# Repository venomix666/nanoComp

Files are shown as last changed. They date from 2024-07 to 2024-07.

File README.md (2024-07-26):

Simple carrier board for the Tang Nano 20K, intended for computer applications.   

The following features interfaces are available:
* USB-C power input with diode protection to avoid back-powering when Tang Nano 20K USB cable is connected
* On/Off switch
* Power LED
* Two USB type A ports.
* UART header for FTDI TTL-232R-3V3 cable
* GPIO header
* Power header with 5V and 3V3 available

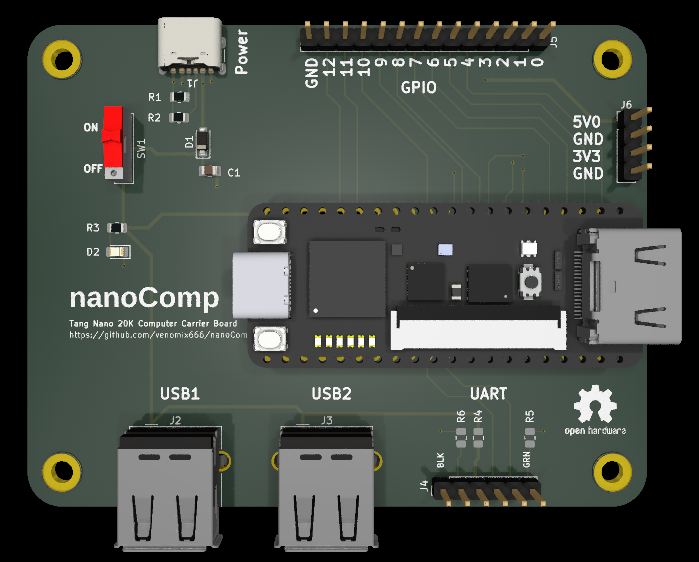
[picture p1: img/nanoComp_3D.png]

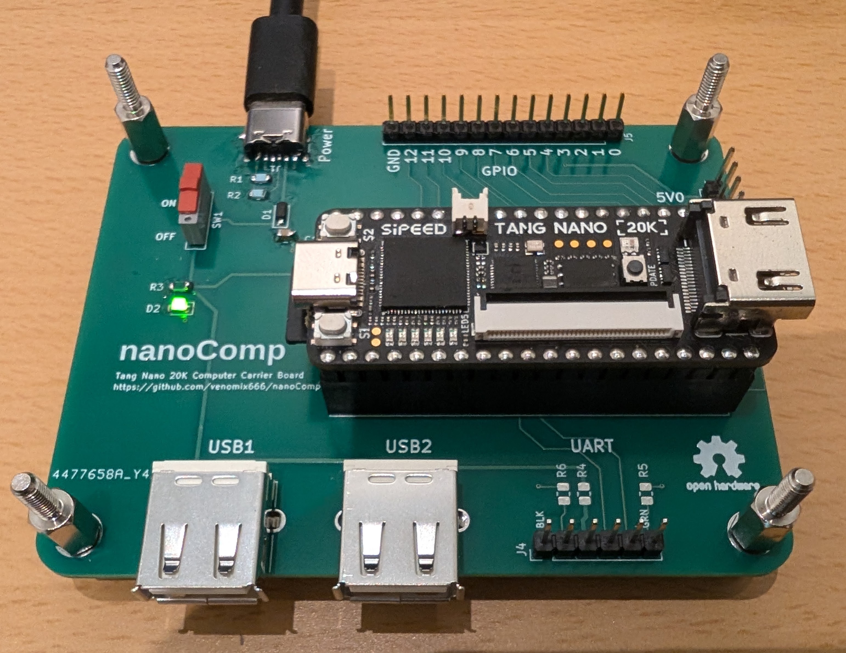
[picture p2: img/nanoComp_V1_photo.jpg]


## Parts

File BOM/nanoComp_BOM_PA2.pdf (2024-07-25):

nanoComp_BOM_PA2

Page 1

nanoComp BOM PA2

# | Reference | Qty | Value | Manufacturer | Manufacturer P/N | Supplier | Supplier P/N

1 | C1 | 1 1uF | | Generic | | Mouser | 603-CC805KKX7R7BB105
2 | D1 | 1 1N5819HW-7-F | | Diodes Inc | 1N5819HW-7-F | Mouser | 621-1N5819HW-F
3 D2 | | 1 LED | | Bivar | SM0805UGC | Mouser | 749-SM0805UGC
4 | J1 | 1 USB_C_Receptacle_PowerOnly_6P | | GCT | USB4125-GF-A | Mouser | 640-USB4125-GF-A
5 | J2,J3 | 2 USB_A | | Molex | 67643-3910 | Mouser | 538-67643-3910
6 J4 | | 1 Conn_01x06_Pin | | Generic | | Mouser | 855-M20-9990646
7 | J5 | 1 Conn_01x14 | | Generic | | Mouser | 538-22-28-4146
8 J6 | | 1 Conn_01x04 | | Generic | | Mouser | 538-22-28-4042
9 R1,R2 | | 2 5k1 | | Generic | | Mouser | 594-MCU08050C5101FP5
10 | R3 | 1 1k | | Generic | | Mouser | 71-TNPW08051K00FEEA
11 | R7,R8,R9,R10 | 4 15k | | Generic | | Mouser | 603-RT0805FRE0715KL
12 | SW1 | 1 SW_Wuerth_450301014042 | | Wurth | 450301014042 | Mouser | 710-450301014042
13 | U1 | 1 N/A | | Sipeed | Tang Nano 20k

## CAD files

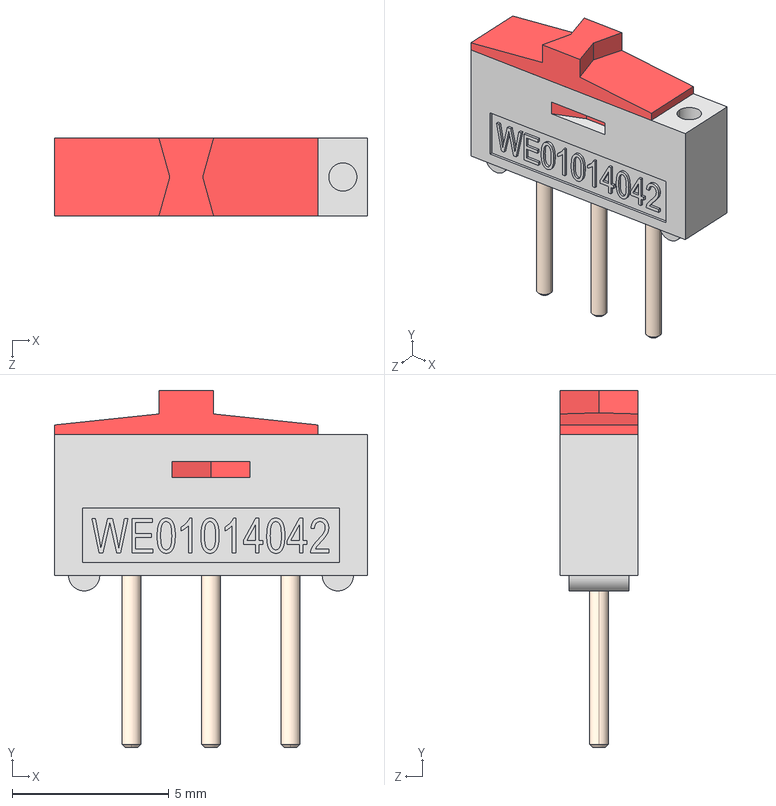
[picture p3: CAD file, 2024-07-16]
3D_models/450301014042.stp
10.0 x 11.4 x 2.50 mm

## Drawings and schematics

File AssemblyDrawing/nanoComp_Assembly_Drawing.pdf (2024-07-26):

1 | 2 | 3 | 4 | 5 | 6

A

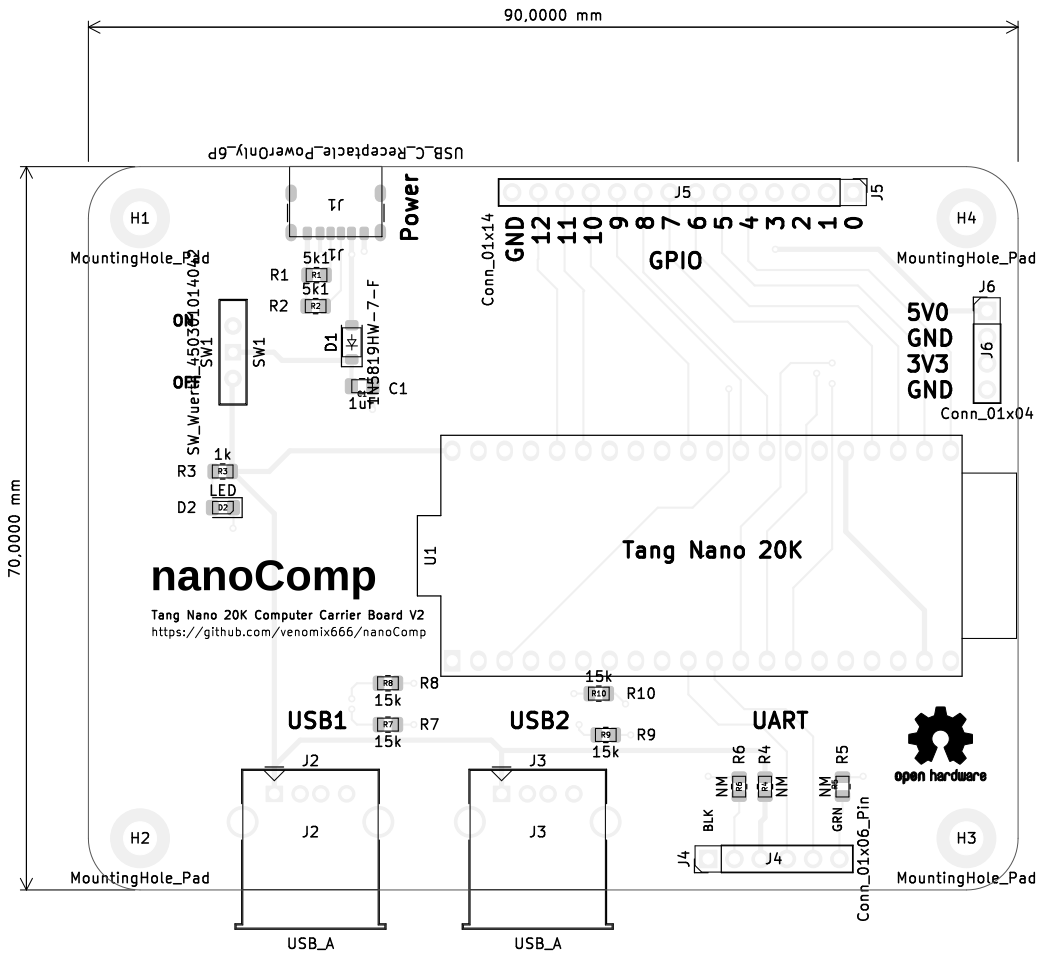
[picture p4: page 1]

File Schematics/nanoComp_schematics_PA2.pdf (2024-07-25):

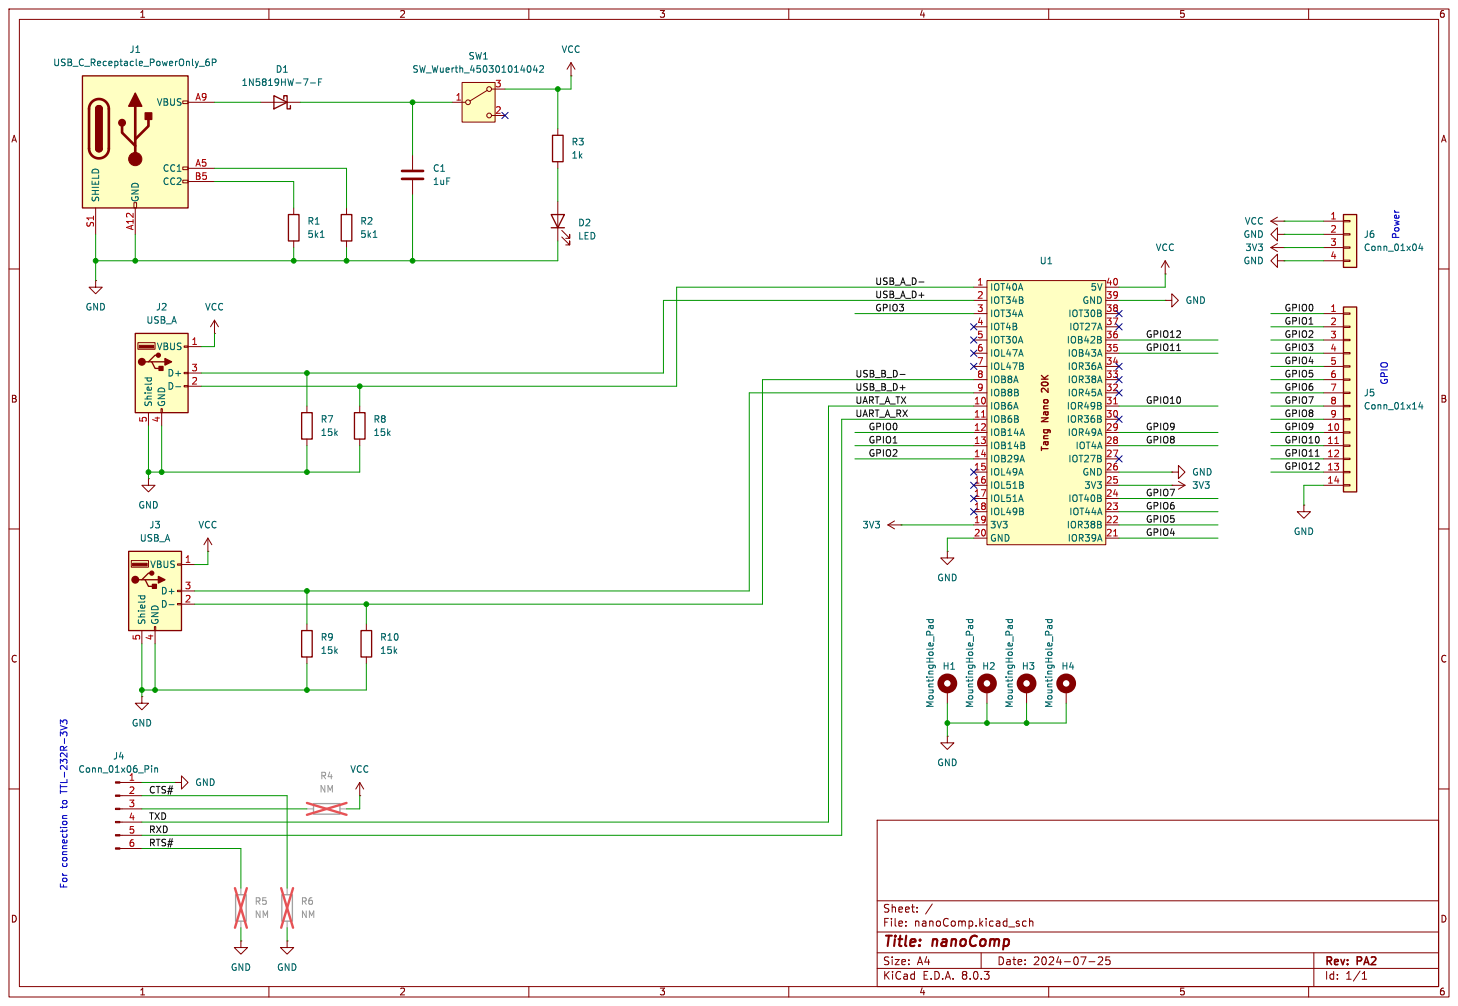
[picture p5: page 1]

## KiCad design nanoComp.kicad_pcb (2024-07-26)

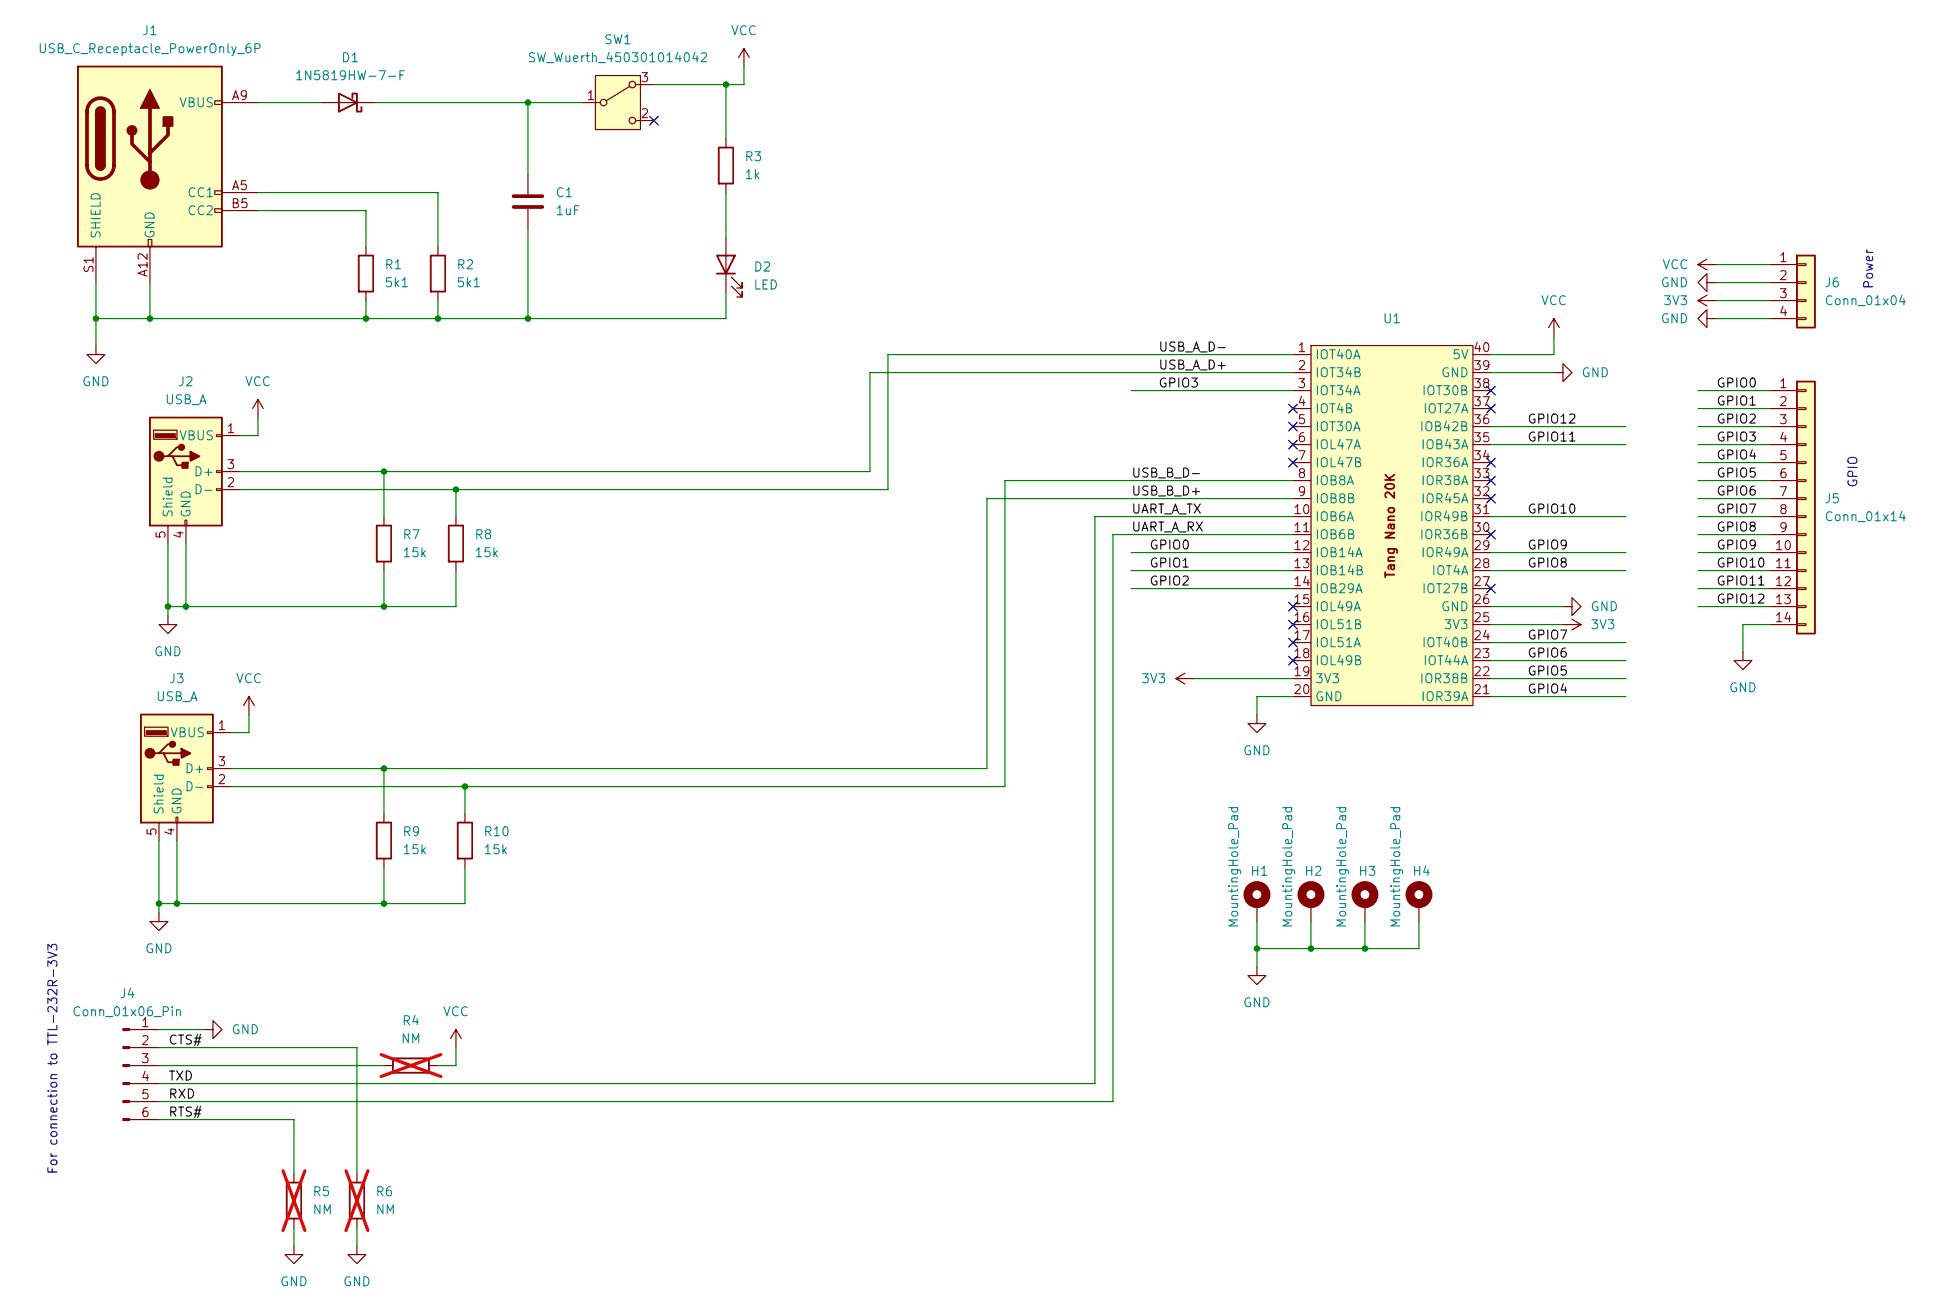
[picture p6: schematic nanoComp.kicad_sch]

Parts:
C1: 1uF; C_0805_2012Metric_Pad1.18x1.45mm_HandSolder
D1: 1N5819HW-7-F; D_SOD-123; Manufacturer P/N 1N5819HW-7-F
D2: LED; LED_0805_2012Metric_Pad1.15x1.40mm_HandSolder; Manufacturer P/N SM0805UGC
H1, H2, H3, H4: MountingHole_Pad; MountingHole_3.2mm_M3_ISO7380_Pad
J1: USB_C_Receptacle_PowerOnly_6P; USB_C_Receptacle_GCT_USB4125-xx-x-0190_6P_TopMnt_Horizontal; Manufacturer P/N USB4125-GF-A
J2, J3: USB_A; USB_A_Molex_67643_Horizontal; Manufacturer P/N 67643-3910
J4: Conn_01x06_Pin; PinHeader_1x06_P2.54mm_Vertical
J5: Conn_01x14; PinHeader_1x14_P2.54mm_Vertical
J6: Conn_01x04; PinHeader_1x04_P2.54mm_Vertical
R1, R2: 5k1; R_0805_2012Metric
R3: 1k; R_0805_2012Metric
R4, R5, R6: NM; R_0805_2012Metric; not fitted
R7, R8, R9, R10: 15k; R_0805_2012Metric
SW1: SW_Wuerth_450301014042; SW_Slide-03_Wuerth-WS-SLTV_10x2.5x6.4_P2.54mm; Manufacturer P/N 450301014042
U1: tangnano20k

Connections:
3V3: J6.3, U1.19 (3V3), U1.25 (3V3)
/CTS#: J4.2, R6.2
/GPIO0: J5.1, U1.12 (IOB14A)
/GPIO1: J5.2, U1.13 (IOB14B)
/GPIO2: J5.3, U1.14 (IOB29A)
/GPIO3: J5.4, U1.3 (IOT34A)
/GPIO4: J5.5, U1.21 (IOR39A)
/GPIO5: J5.6, U1.22 (IOR38B)
/GPIO6: J5.7, U1.23 (IOT44A)
/GPIO7: J5.8, U1.24 (IOT40B)
/GPIO8: J5.9, U1.28 (IOT4A)
/GPIO9: J5.10, U1.29 (IOR49A)
/GPIO10: J5.11, U1.31 (IOR49B)
/GPIO11: J5.12, U1.35 (IOB43A)
/GPIO12: J5.13, U1.36 (IOB42B)
/RTS#: J4.6, R5.2
/RXD: J4.5, U1.11 (IOB6B)
/TXD: J4.4, U1.10 (IOB6A)
/USB_A_D+: J2.3 (D+), R7.1, U1.2 (IOT34B)
/USB_A_D-: J2.2 (D-), R8.1, U1.1 (IOT40A)
/USB_B_D+: J3.3 (D+), R9.1, U1.9 (IOB8B)
/USB_B_D-: J3.2 (D-), R10.1, U1.8 (IOB8A)
GND: C1.2, D2.1 (K), H1.1, H2.1, H3.1, H4.1, J1.A12 (GND), J1.B12 (GND), J1.S1 (SHIELD), J2.4 (GND), J2.5 (Shield), J3.4 (GND), J3.5 (Shield), J4.1, J5.14, J6.2, J6.4, R1.2, R2.2, R5.1, R6.1, R7.2, R8.2, R9.2, R10.2, U1.20 (GND), U1.26 (GND), U1.39 (GND)
unnamed: D1.2 (A), J1.A9 (VBUS), J1.B9 (VBUS)
unnamed: C1.1, D1.1 (K), SW1.1 (B)
unnamed: D2.2 (A), R3.2
unnamed: J1.A5 (CC1), R2.1
unnamed: J1.B5 (CC2), R1.1
unnamed: J4.3, R4.1
VCC: J2.1 (VBUS), J3.1 (VBUS), J6.1, R3.1, R4.2, SW1.3 (A), U1.40 (5V)

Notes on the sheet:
For connection to TTL-232R-3V3
GPIO
Power

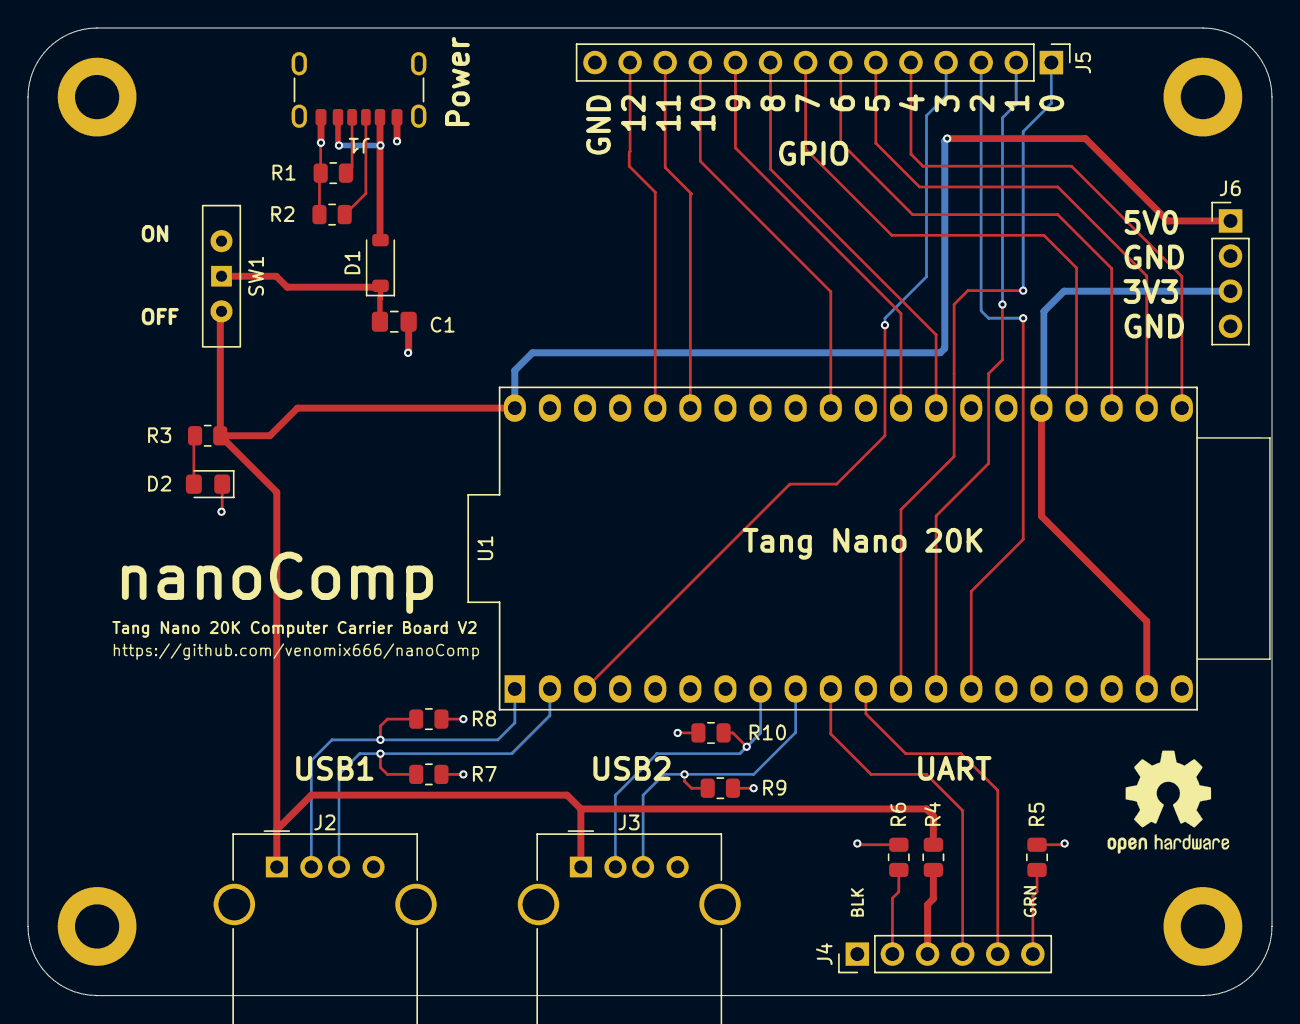
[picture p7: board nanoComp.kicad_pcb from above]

Board: 2 copper layers, 90.0 x 70.0 mm, 25 parts (0 on the bottom side), 30 nets.

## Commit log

2024-07-10 Initial commit of board, more or less ready
    [nanoComp.kicad_pcb, nanoComp.kicad_sch]
2024-07-10 Added PDF schematics
2024-07-15 Finishing touches + manufacturing files
    [nanoComp-B_Cu.gbr, nanoComp-B_Mask.gbr, nanoComp-B_Paste.gbr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]
2024-07-15 Schematics cleanup
2024-07-16 Added step model of Tang Nano 20K board + rendered image of board
    [nanoComp.kicad_pcb]
2024-07-16 Added 3D model for power switch and updated board image
    [450301014042.stp, nanoComp.kicad_pcb]
2024-07-16 Added assembly drawing
2024-07-25 Added 15k pulldowns on USB data lines for master configuration
    [nanoComp-B_Cu.gbr, nanoComp-B_Mask.gbr, nanoComp-B_Silkscreen.gbr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]
2024-07-26 Updated assembly drawing and added 3D model of board
    [450301014042.stp, nanoComp.kicad_pcb]
